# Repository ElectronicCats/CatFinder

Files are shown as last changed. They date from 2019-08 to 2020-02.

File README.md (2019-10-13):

# CatFinder

The Electronic Cats along with The Inventor's House have developed a new development kit for a Mars Rover in which almost everyone can participate

"The CatFinder" is an exploration vehicle that collects data from the environment in which it travels.

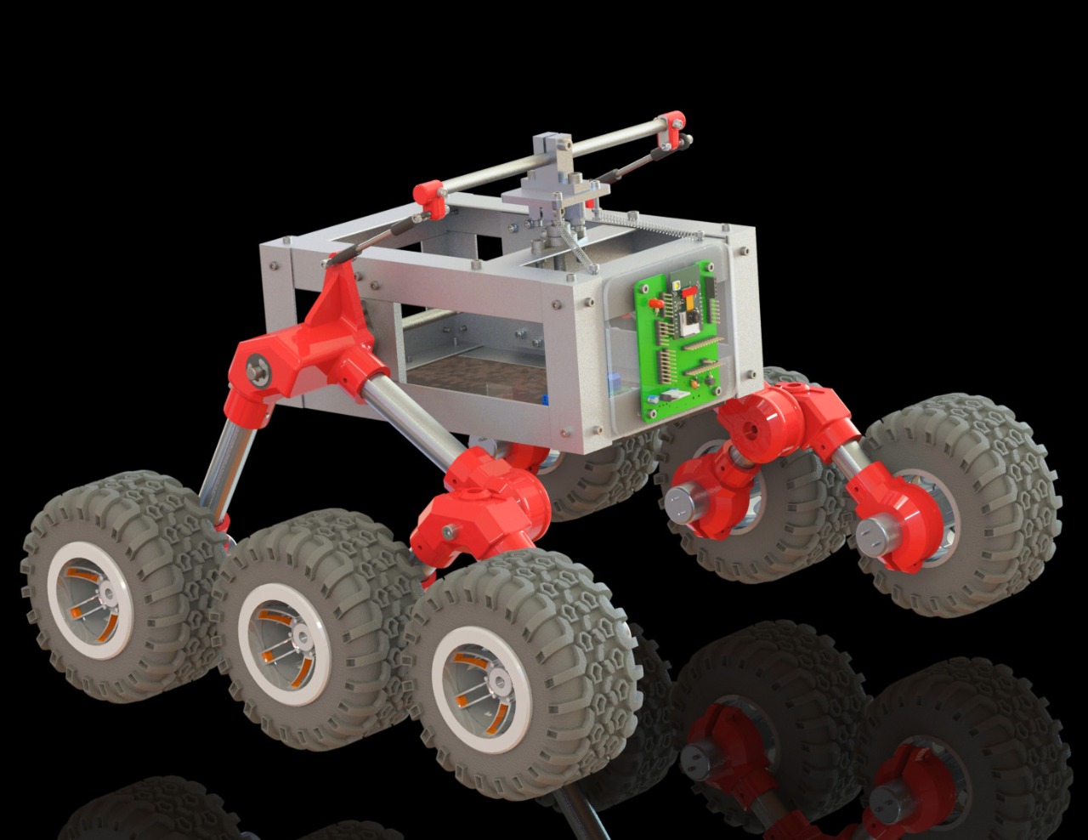
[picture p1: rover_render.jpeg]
Rover Render


The CatFinder Rover is cappable of transmit:

- Humidity
- Atmosphere pressure
- Temperature 
- CO2 levels in ppm
- TVOC levels in ppb 
- Position with acelerometer and gyroscope
- Video broadcasting.

Yes! we're capable of getting data, control the motors and transmitting video, through WiFi thanks to the ESP32-CAM and the [Bast Pro Mini](https://github.com/ElectronicCats/Bast-Pro-Mini-M0) (Which is a devBoard fully compatible with the Arduino Pro Mini).

## Licence ##

Firmware released under an GNU AGPL v3.0 license. See the LICENSE file for more information.

Hardware released under an CERN Open Hardware Licence v1.2. See the LICENSE_HARDWARE file for more information.

Electronic Cats is a registered trademark, please do not use if you sell these PCBs.

Electronic Cats invests time and resources providing this open source design, please support Electronic Cats and open-source hardware by purchasing products from Electronic Cats!

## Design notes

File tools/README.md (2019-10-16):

# TEXT_TRANSFORM_C v1.0

Esta herramienta creada en c# tiene la función de transformar código HTML, JS y CSS o cualquier otro a texto de C,
con el fin de poder minificar código, ahorrando tiempo y espacio en memoria



Esta herramienta se encuentra como un ejecutable en la carpeta de ```/tools``` de este repositorio

# Ejecutable
 
Esta herramienta es solamente compatible con el sistema operativo  ```windows```, instrucciones de ejecución: 

* Abrir el ejecutable que encontramos dentro del repo en la carpeta  ```/tools``` el archivo ```tool_transformC_text.exe```


# Forma de uso

  * Iniciar la aplicación con doble click en el ejecutable, aparecerá lo siguiente
  * 
  
  
  * Una vez iniciado el programa se puede crear la web en algún editor de texto y pasarlo a la aplicación con solo copiar y pegar en la consola tu codigo, como el ejemplo siguiente:

 ```
 <!DOCTYPE html>
<html lang="en">
<head>
    <meta charset="UTF-8">
    <meta name="viewport" content="width=device-width, initial-scale=1.0">
    <meta http-equiv="X-UA-Compatible" content="ie=edge">
    <title>EJEMPLO DE USO</title>
</head>
<style>
    *{
        margin: 0;
        padding: 0;
    }
    body{
        background-color: #f2f2f2;
    }
</style>
<body>
    <h1 class="title">Cat Finder</h1>
    <img src="https://electroniccats.com/wp-content/uploads/2018/01/logo-75.png" alt="Logo" />
    <p class="subtitle center">:3</p>
    <script>
        console.log('Son chidos los de Electronic Cats!');
    </script>
</body>
</html>
 ```
 Con esto se obtendra el codigo listo para C y quedara de la siguiente forma:
 
 
 
 * Una vez listo para concluir solo es necesario presionar enter y escribir ```ok.``` después de haber hecho esto nos se obtendra la siguiente salida
 
 ```<!DOCTYPE html><html lang=\"en\"><head><meta charset=\"UTF-8\"><meta name=\"viewport\" content=\"width=device-width, initial-scale=1.0\"><meta http-equiv=\"X-UA-Compatible\" content=\"ie=edge\"><title>EJEMPLO DE USO</title></head><style>*{margin: 0;padding: 0;}body{background-color: #f2f2f2;}</style><body><h1 class=\"title\">Cat Finder</h1>\"Logo\"<p class=\"subtitle center\">:3</p><script>console.log('Son chidos los de Electronic Cats!')</script></body></html>```
 
 listo para pegar en una sola linea de codigo en C, como el siguiente ejemplo
 
```SendData = "<!DOCTYPE html><html lang=\"en\"><head><meta charset=\"UTF-8\"><meta name=\"viewport\" content=\"width=device-width, initial-scale=1.0\"><meta http-equiv=\"X-UA-Compatible\" content=\"ie=edge\"><title>EJEMPLO DE USO</title></head><style>*{margin: 0;padding: 0;}body{background-color: #f2f2f2;}</style><body><h1 class=\"title\">Cat Finder</h1><img src=\"https://electroniccats.com/wp-content/uploads/2018/01/logo-75.png\" alt=\"Logo\" /><p class=\"subtitle center\">:3</p><script>console.log('Son chidos los de Electronic Cats!')</script></body></html>";```

# Recomendaciones

  * Es importante saber que cada línea de código escrita con js tendra que terminar con su ```;``` ya que al final de el proceso se entrega una sola linea de codigo y esto en js marcaria un error al momento de ejecutarlo en el navegador si no termina cada línea con su ```;```

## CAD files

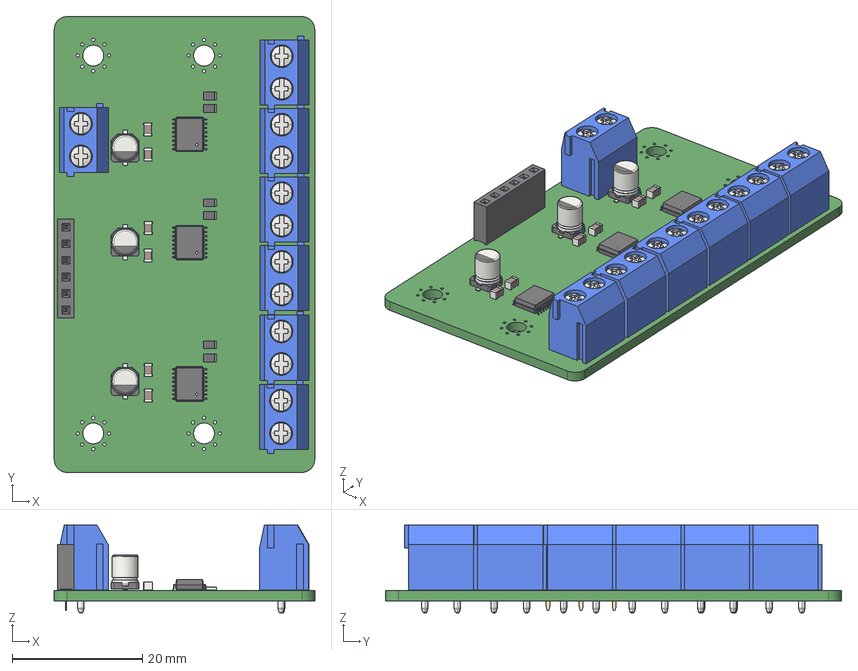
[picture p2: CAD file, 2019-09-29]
Electronics/Hardware/cat_finder_motors/cat_finder_motors.stp
40.0 x 70.0 x 13.5 mm

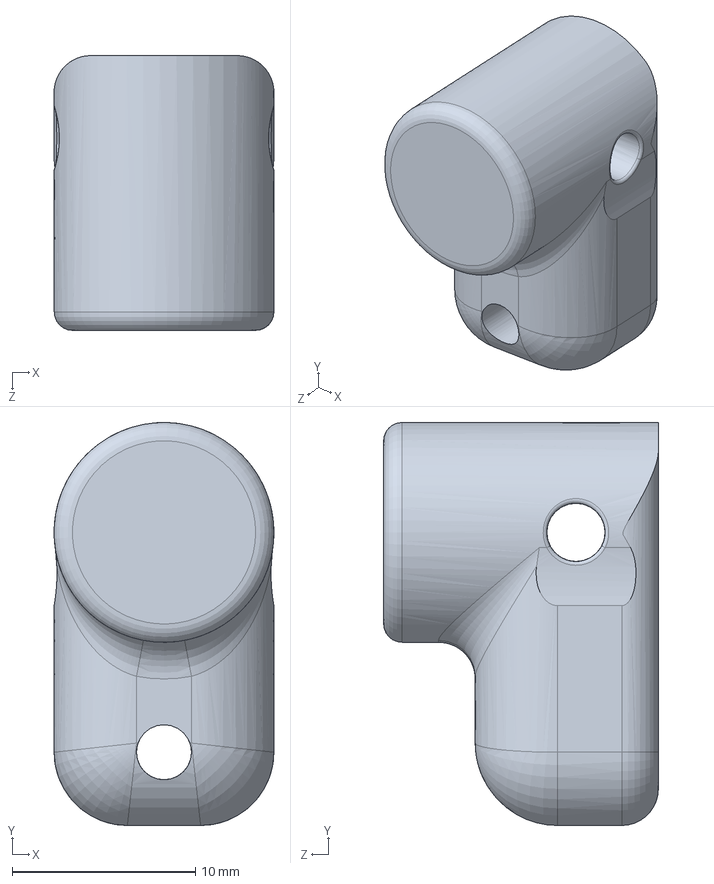
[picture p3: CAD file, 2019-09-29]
Mechanics/3D_Printing/SLDPRT/Tapon2.SLDPRT
12.0 x 22.0 x 15.0 mm

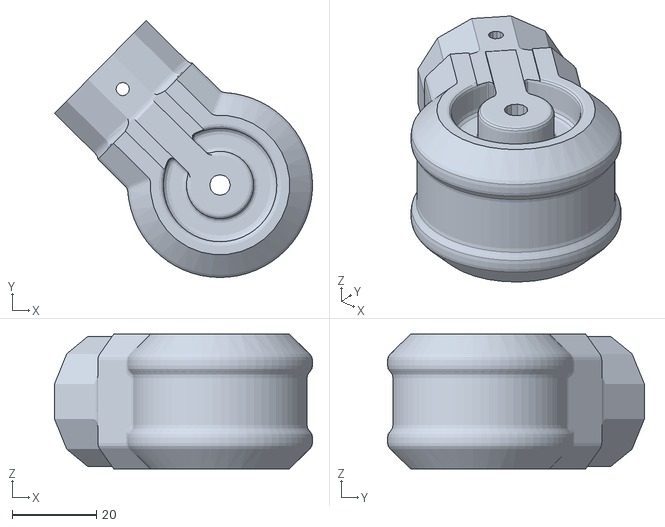
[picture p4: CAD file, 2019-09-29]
Mechanics/3D_Printing/Stl/Union_Y_delantera1.STL
61.4 x 61.1 x 32.0

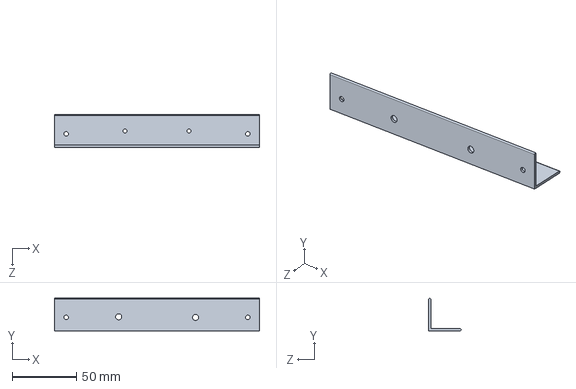
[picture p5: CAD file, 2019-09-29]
Mechanics/SolidWorks/Frontales de Caja.SLDPRT
160.0 x 25.4 x 25.4 mm

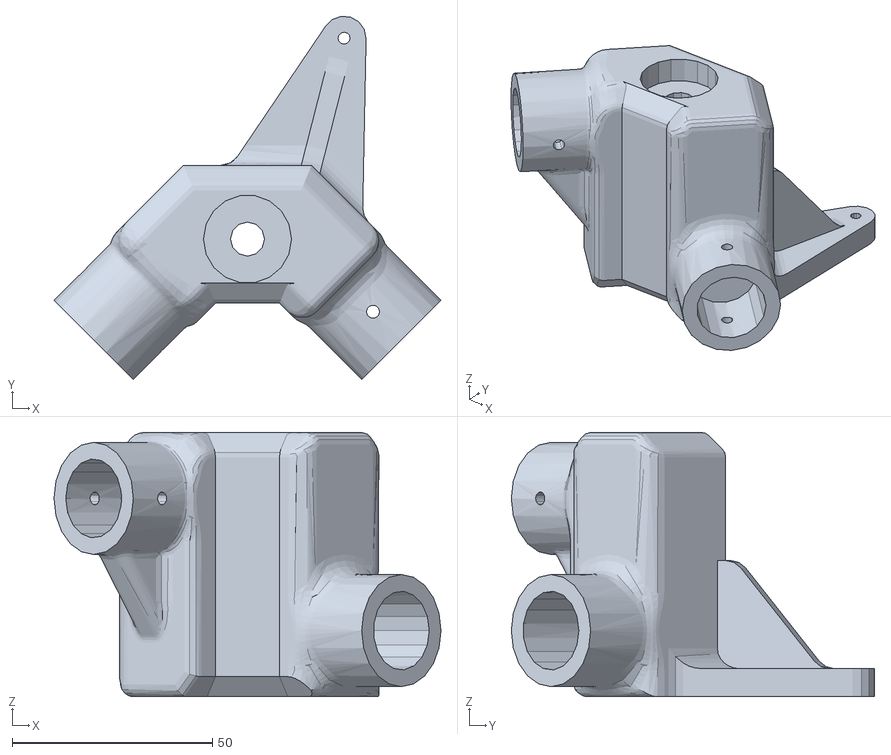
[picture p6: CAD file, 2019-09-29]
Mechanics/3D_Printing/Stl/doble2.STL
96.6 x 90.7 x 66.0

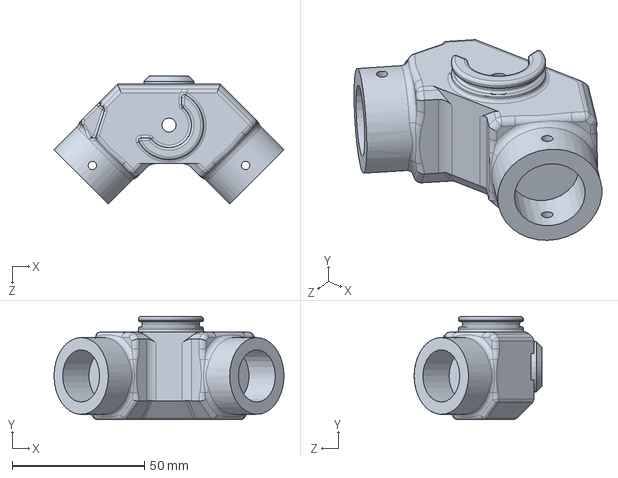
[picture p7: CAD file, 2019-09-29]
Mechanics/3D_Printing/SLDPRT/Ydelantera1.sldprt
86.8 x 39.0 x 48.2 mm

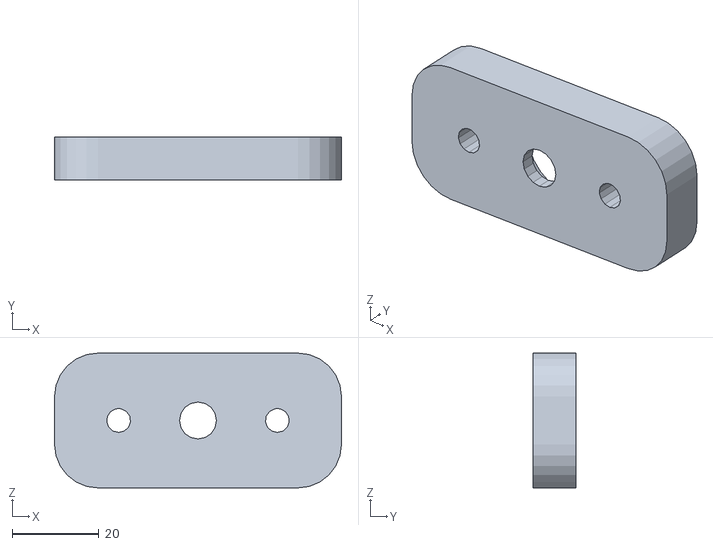
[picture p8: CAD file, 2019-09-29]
Mechanics/3D_Printing/Stl/soporte baleros.STL
66.0 x 10.0 x 31.0

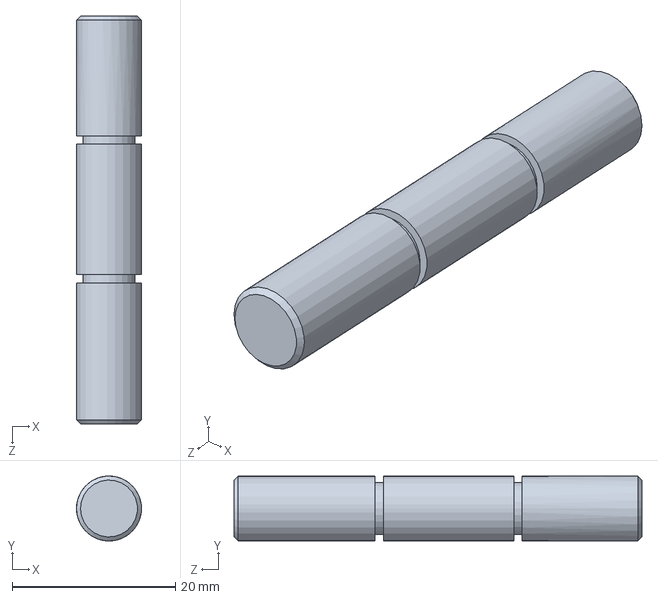
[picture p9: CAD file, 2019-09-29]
Mechanics/SolidWorks/Mini eje.SLDPRT
7.98 x 7.96 x 50.0 mm

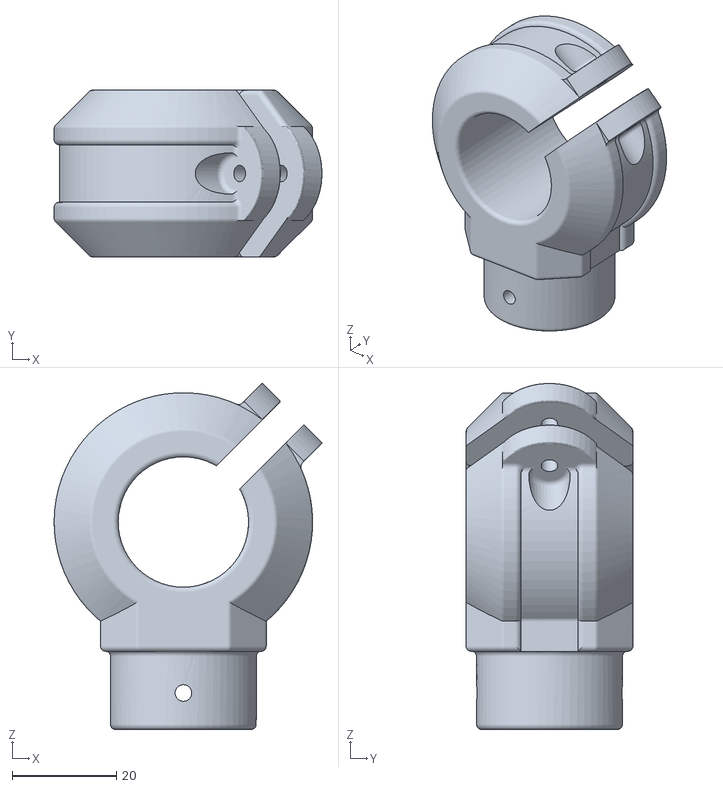
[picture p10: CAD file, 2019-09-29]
Mechanics/3D_Printing/Stl/Ruedas_Suport.STL
51.4 x 32.0 x 66.4

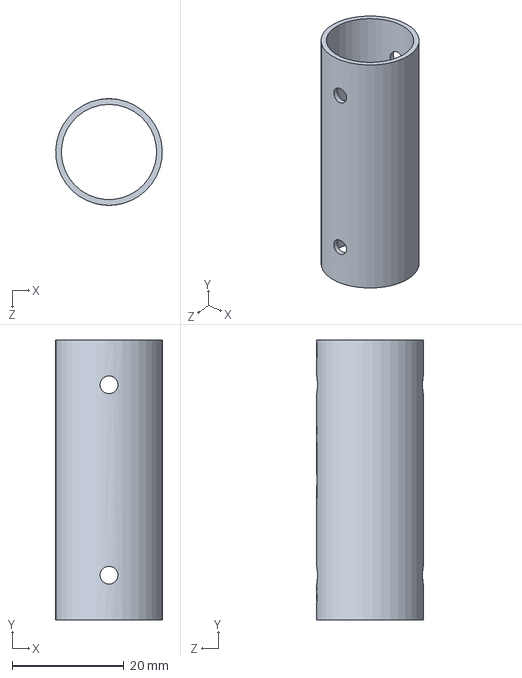
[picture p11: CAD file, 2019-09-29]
Mechanics/SolidWorks/tubo50mm.SLDPRT
19.0 x 50.0 x 19.1 mm

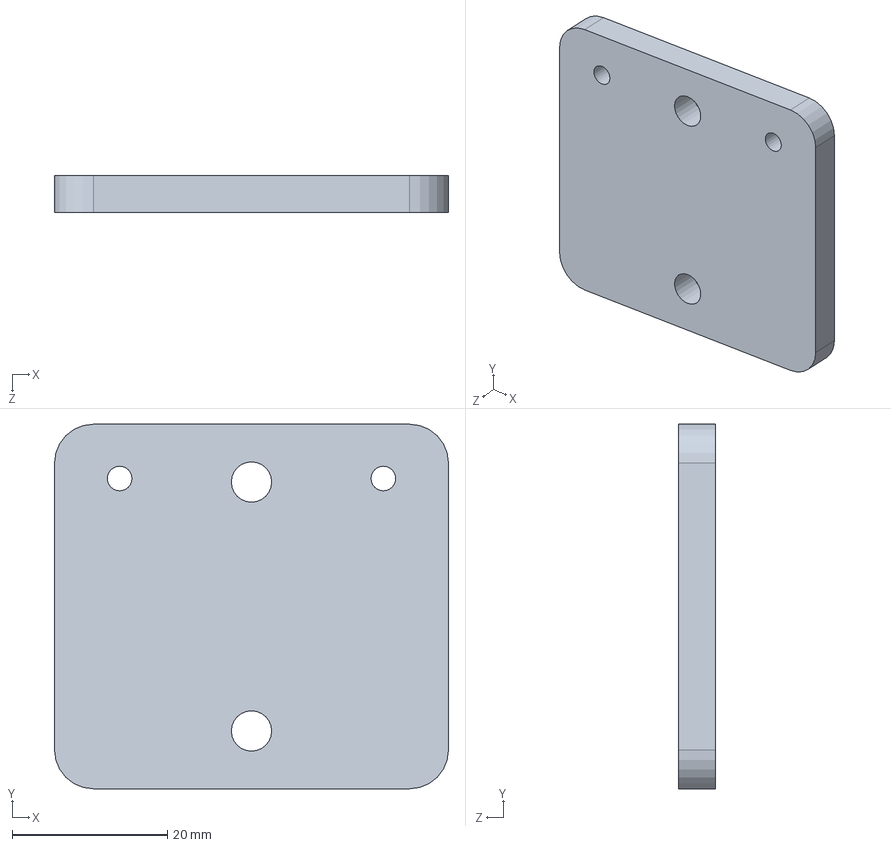
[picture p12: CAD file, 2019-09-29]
Mechanics/SolidWorks/Lamina para sk8.SLDPRT
50.8 x 47.0 x 4.76 mm

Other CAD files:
Mechanics/3D_Printing/SLDPRT/Tapon1.SLDPRT
Mechanics/3D_Printing/SLDPRT/YGeneral1.SLDPRT
Mechanics/3D_Printing/SLDPRT/YGeneral2.SLDPRT
Mechanics/3D_Printing/Stl/doble1.STL
Mechanics/3D_Printing/SLDPRT/Ydelantera2.sldprt
Mechanics/3D_Printing/Stl/Union_Y_delantera2.STL
Mechanics/3D_Printing/SLDPRT/Union a Y delantera 1.SLDPRT
Mechanics/3D_Printing/SLDPRT/Union a Y delantera2.SLDPRT
Mechanics/3D_Printing/Stl/Tapon1.STL
Mechanics/3D_Printing/Stl/Tapon2.STL
Mechanics/3D_Printing/Stl/Y_delantera1.STL
Mechanics/3D_Printing/Stl/Y_delantera2.STL
Mechanics/SolidWorks/Acrilico Base.SLDPRT
Mechanics/SolidWorks/Acrilico frontal.SLDPRT
Mechanics/SolidWorks/Acrilico.SLDPRT
Mechanics/SolidWorks/Ajuste de rotulas.SLDPRT
Mechanics/SolidWorks/Balero 608.SLDPRT
Mechanics/SolidWorks/Base para Chumacera.SLDPRT
Mechanics/SolidWorks/Base para resortes .SLDPRT
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

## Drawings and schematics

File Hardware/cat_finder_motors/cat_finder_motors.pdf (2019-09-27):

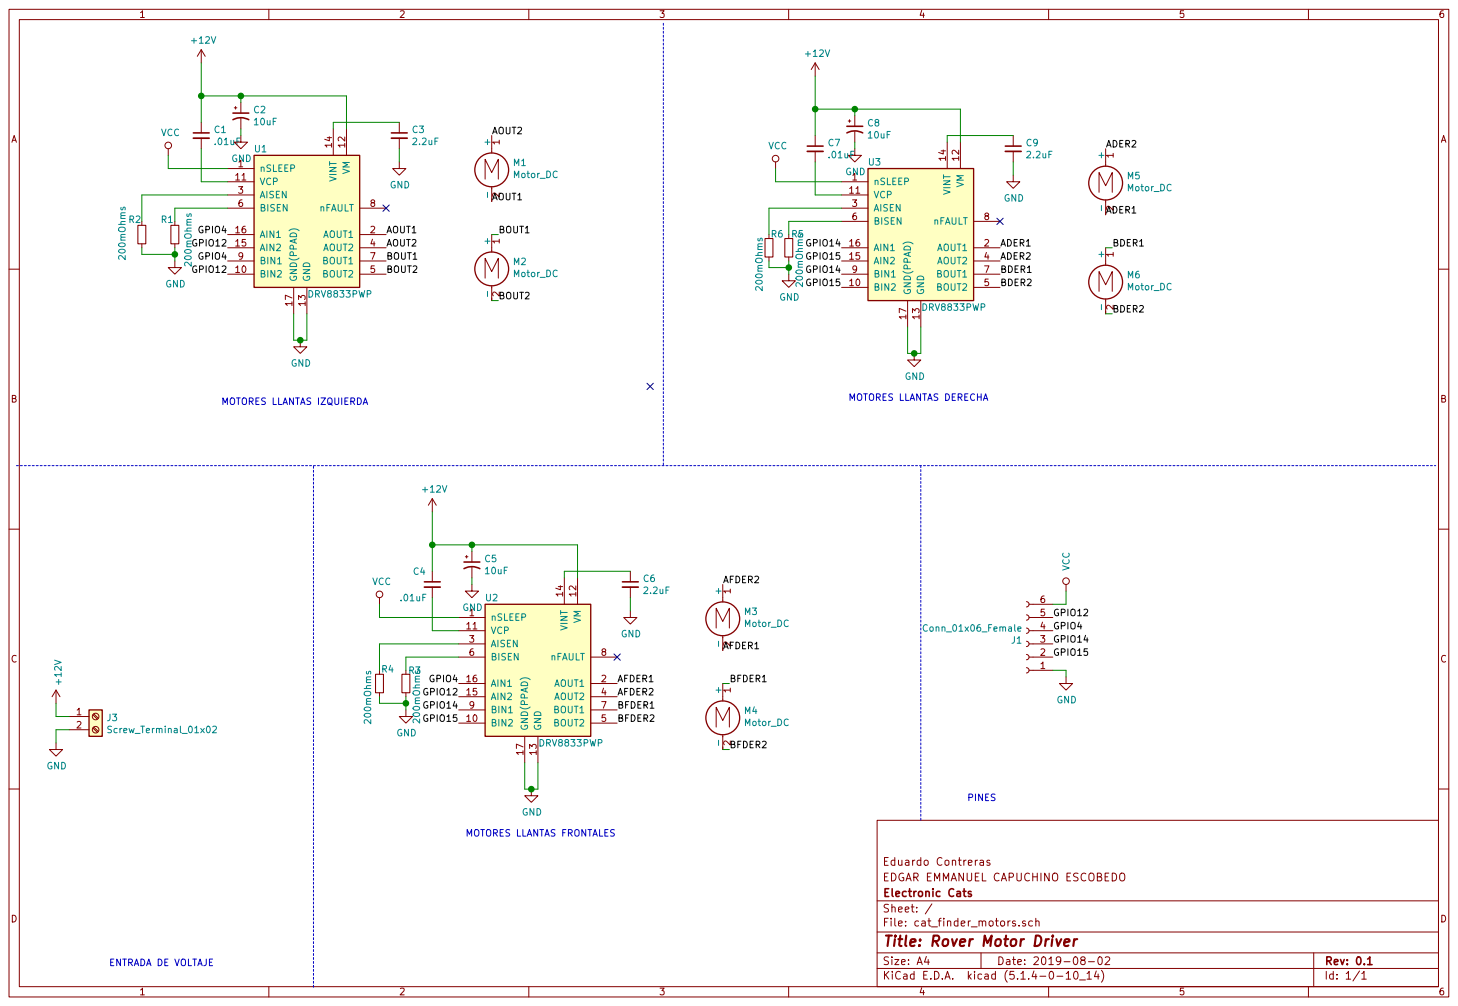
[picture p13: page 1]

Eduardo Contreras
File: cat_finder_motors.sch Sheet: / Electronic Cats EDGAR EMMANUEL CAPUCHINO ESCOBEDO

Id: 1/1 Title: Rover Motor Driver

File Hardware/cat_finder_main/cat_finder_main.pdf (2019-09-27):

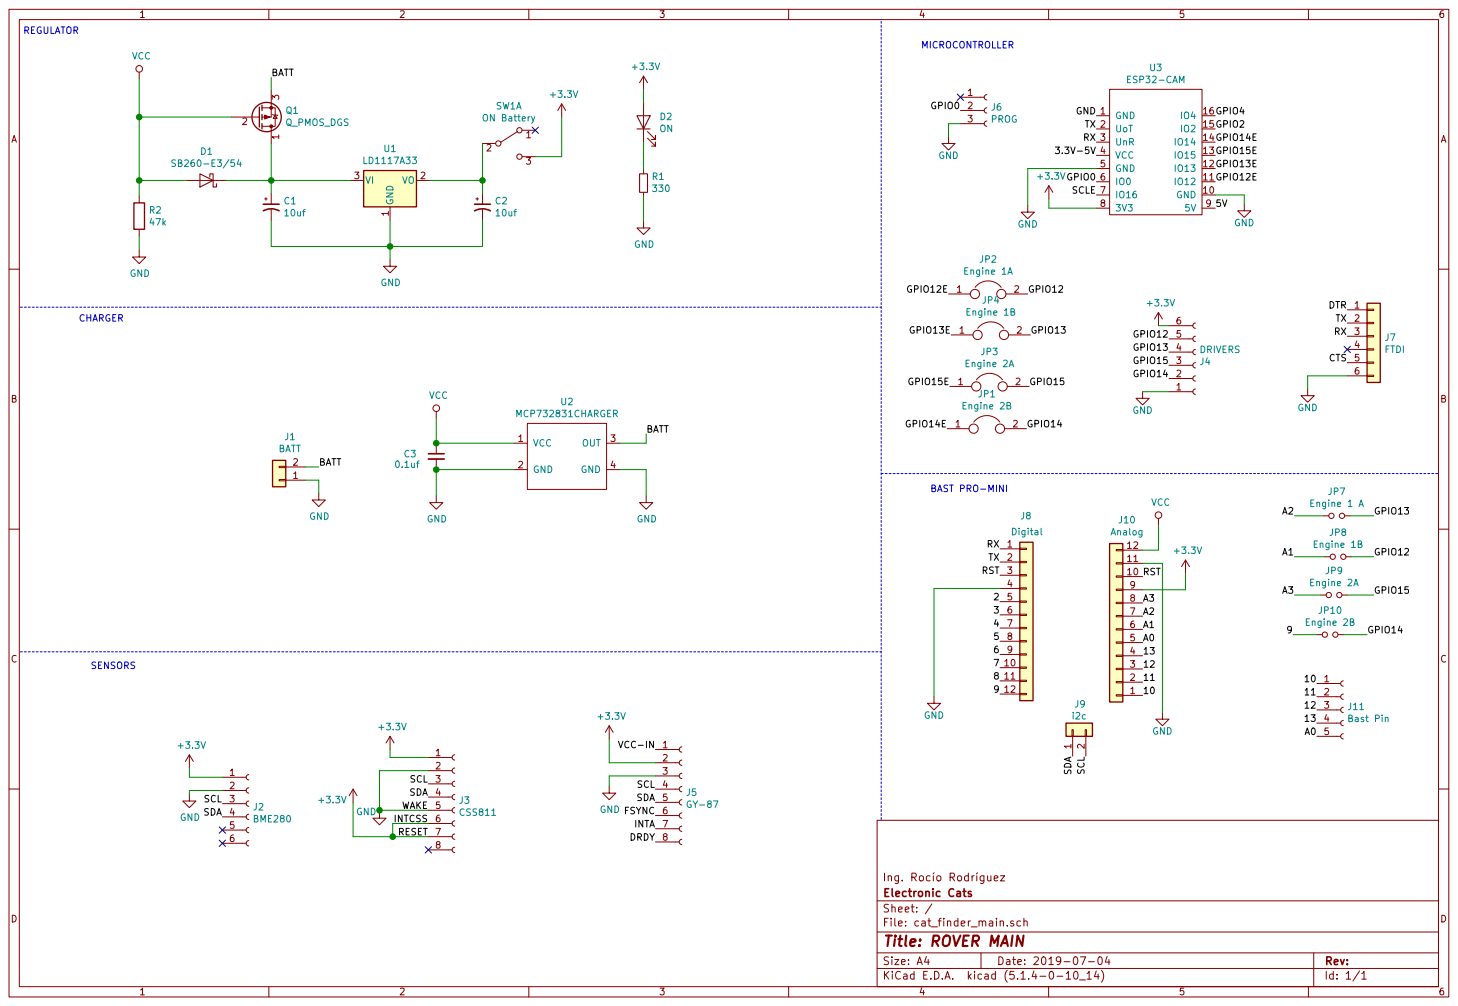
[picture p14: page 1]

Ing. Rocío Rodríguez
File: cat_finder_main.sch Sheet: / Electronic Cats

Id: 1/1 Title: ROVER MAIN

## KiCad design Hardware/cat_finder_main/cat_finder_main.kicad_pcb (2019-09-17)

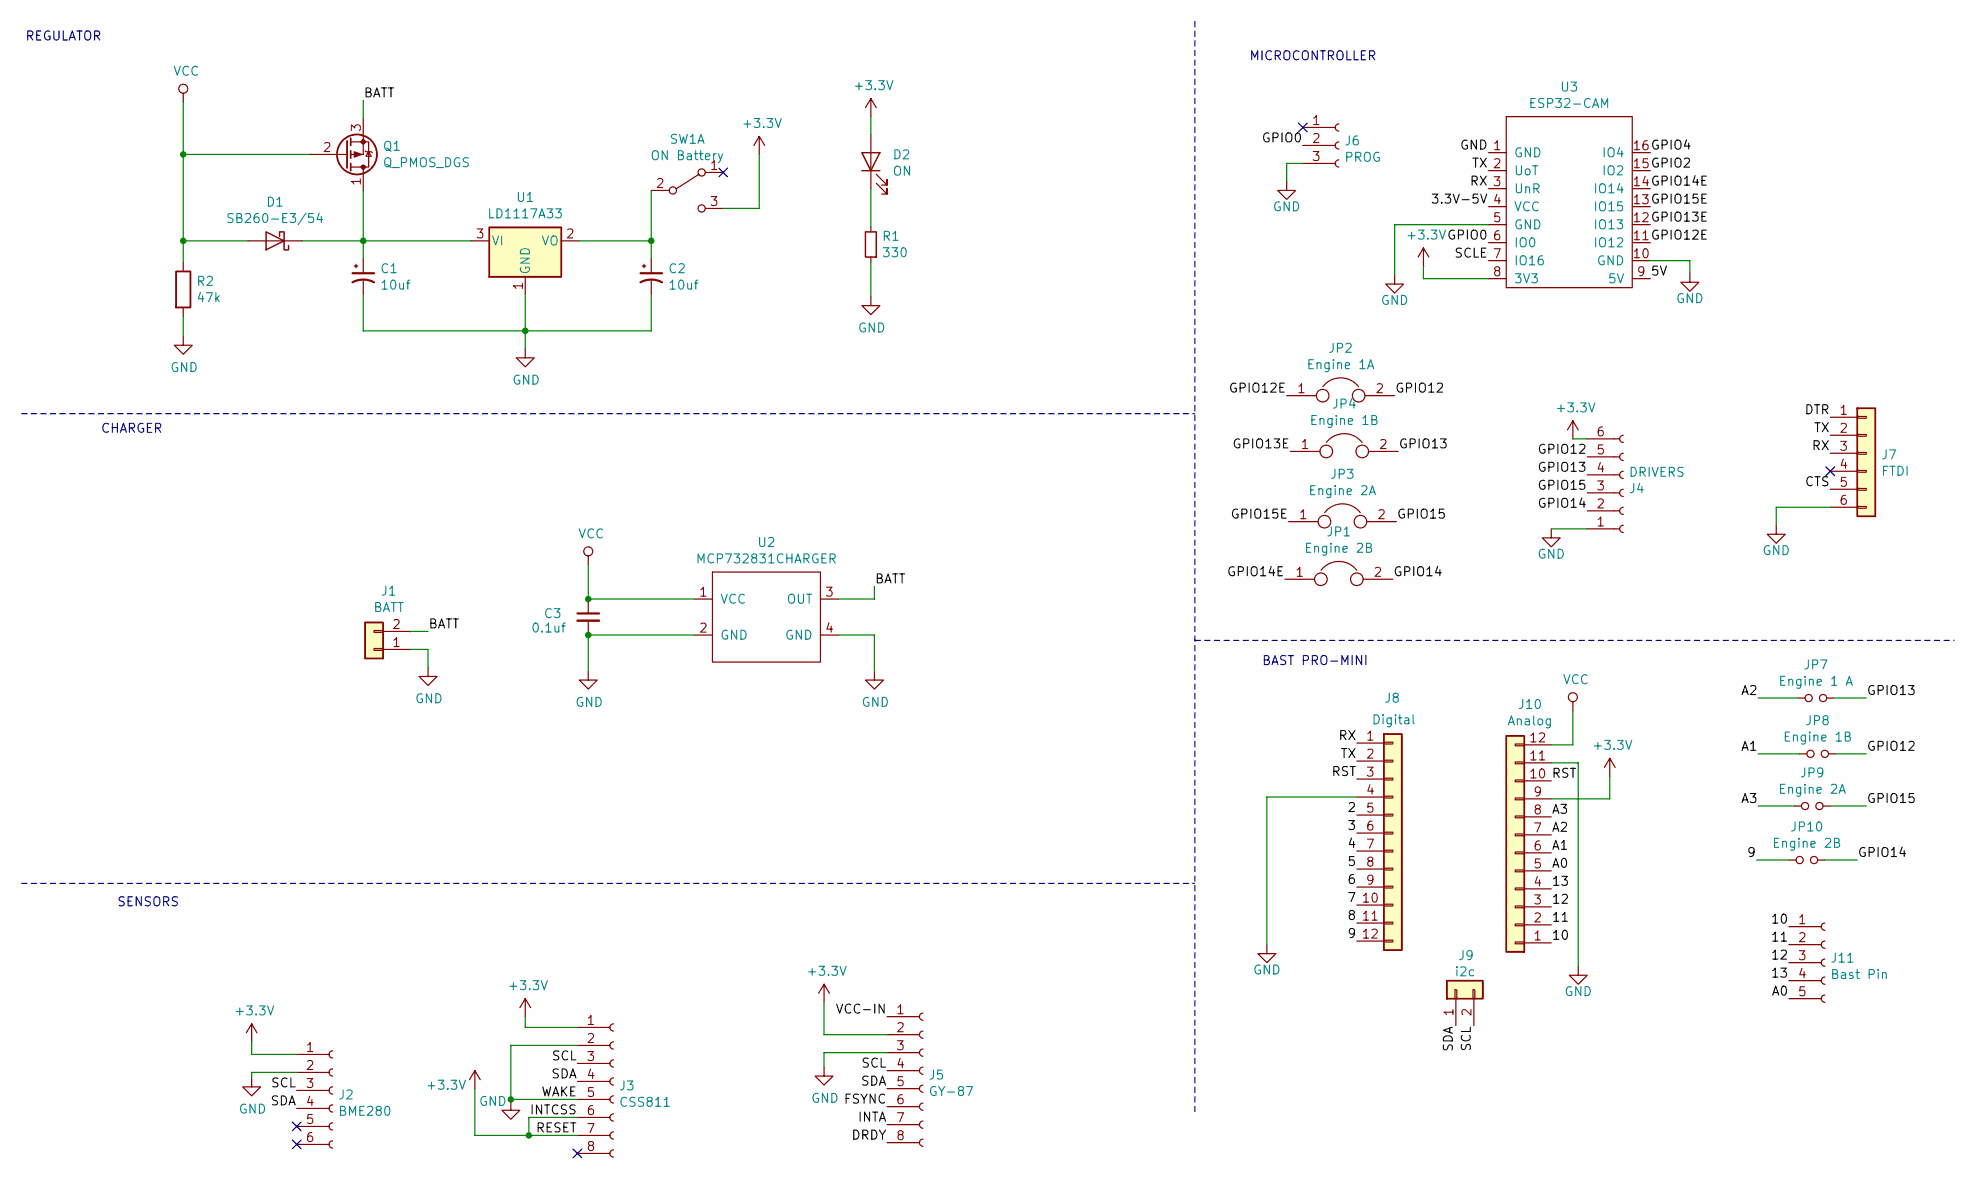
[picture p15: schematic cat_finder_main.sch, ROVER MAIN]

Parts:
C1, C2: 10uf; CP_Radial_D5.0mm_P2.00mm
C3: 0.1uf; C_Disc_D5.0mm_W2.5mm_P5.00mm
D1: SB260-E3/54; D_A-405_P7.62mm_Horizontal
D2: ON; LED_D5.0mm
J1: BATT; TerminalBlock_bornier-2_P5.08mm
J2: BME280; PinHeader_1x06_P2.54mm_Vertical
J3: CSS811; PinHeader_1x08_P2.54mm_Vertical
J4: DRIVERS; PinHeader_1x06_P2.54mm_Vertical
J5: GY-87; PinHeader_1x08_P2.54mm_Vertical
J6: PROG; PinHeader_1x03_P2.54mm_Vertical
J7: FTDI; PinHeader_1x06_P2.54mm_Vertical
J8: Digital; PinHeader_1x12_P2.54mm_Vertical
J9: i2c; PinHeader_1x02_P2.54mm_Vertical
J10: Analog; PinHeader_1x12_P2.54mm_Vertical
J11: Bast Pin; PinSocket_1x05_P2.54mm_Vertical
JP1: Engine 2B; SolderJumper-2_P1.3mm_Bridged_RoundedPad1.0x1.5mm
JP2: Engine 1A; SolderJumper-2_P1.3mm_Bridged_RoundedPad1.0x1.5mm
JP3: Engine 2A; SolderJumper-2_P1.3mm_Bridged_RoundedPad1.0x1.5mm
JP4: Engine 1B; SolderJumper-2_P1.3mm_Bridged_RoundedPad1.0x1.5mm
JP7: Engine 1 A; SolderJumper-2_P1.3mm_Open_RoundedPad1.0x1.5mm
JP8: Engine 1B; SolderJumper-2_P1.3mm_Open_RoundedPad1.0x1.5mm
JP9: Engine 2A; SolderJumper-2_P1.3mm_Open_RoundedPad1.0x1.5mm
JP10: Engine 2B; SolderJumper-2_P1.3mm_Open_RoundedPad1.0x1.5mm
Q1: Q_PMOS_DGS; TO-92_Inline
R1: 330; R_Axial_DIN0207_L6.3mm_D2.5mm_P10.16mm_Horizontal
R2: 47k; R_Axial_DIN0207_L6.3mm_D2.5mm_P10.16mm_Horizontal
SW1: ON Battery; SW_1825116-1
U1: LD1117A33; TO-220-3_Vertical
U2: MCP732831CHARGER; charger_EC_3.3V_battery
U3: ESP32-CAM

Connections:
+3V3: D2.2 (A), J2.1, J3.1, J3.6, J3.7, J4.6, J5.2, J10.9, SW1.3 (C), U3.8 (3V3)
/2: J8.5
/3: J8.6
/3.3V-5V: U3.4 (VCC)
/4: J8.7
/5: J8.8
/5V: U3.9 (5V)
/6: J8.9
/7: J8.10
/8: J8.11
/9: J8.12, JP10.1
/10: J10.1, J11.1
/11: J10.2, J11.2
/12: J10.3, J11.3
/13: J10.4, J11.4
/A0: J10.5, J11.5
/A1: J10.6, JP8.1
/A2: J10.7, JP7.1
/A3: J10.8, JP9.1
/BATT: J1.2, Q1.3 (S), U2.3 (OUT)
/CTS: J7.5
/DRDY: J5.8
/DTR: J7.1
/FSYNC: J5.6
/GPIO0: J6.2, U3.6 (IO0)
/GPIO2: U3.15 (IO2)
/GPIO4: U3.16 (IO4)
/GPIO12: J4.5, JP2.2, JP8.2
/GPIO12E: JP2.1, U3.11 (IO12)
/GPIO13: J4.4, JP4.2, JP7.2
/GPIO13E: JP4.1, U3.12 (IO13)
/GPIO14: J4.2, JP1.2, JP10.2
/GPIO14E: JP1.1, U3.14 (IO14)
/GPIO15: J4.3, JP3.2, JP9.2
/GPIO15E: JP3.1, U3.13 (IO15)
/INTA: J5.7
/RST: J8.3, J10.10
/RX: J7.3, J8.1, U3.3 (UnR)
/SCL: J2.3, J3.3, J5.4, J9.2
/SCLE: U3.7 (IO16)
/SDA: J2.4, J3.4, J5.5, J9.1
/TX: J7.2, J8.2, U3.2 (UoT)
/VCC-IN: J5.1
GND: C1.2, C2.2, C3.2, J1.1, J2.2, J3.2, J3.5, J4.1, J5.3, J6.3, J7.6, J8.4, J10.11, R1.1, R2.2, U1.1 (GND), U2.2 (GND), U2.4 (GND), U3.1 (GND), U3.5 (GND), U3.10 (GND)
unnamed: C1.1, D1.1 (K), Q1.1 (D), U1.3 (VI)
unnamed: C2.1, SW1.2 (B), U1.2 (VO)
unnamed: D2.1 (K), R1.2
VCC: C3.1, D1.2 (A), J10.12, Q1.2 (G), R2.1, U2.1 (VCC)

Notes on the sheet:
REGULATOR
CHARGER
SENSORS
MICROCONTROLLER
BAST PRO-MINI

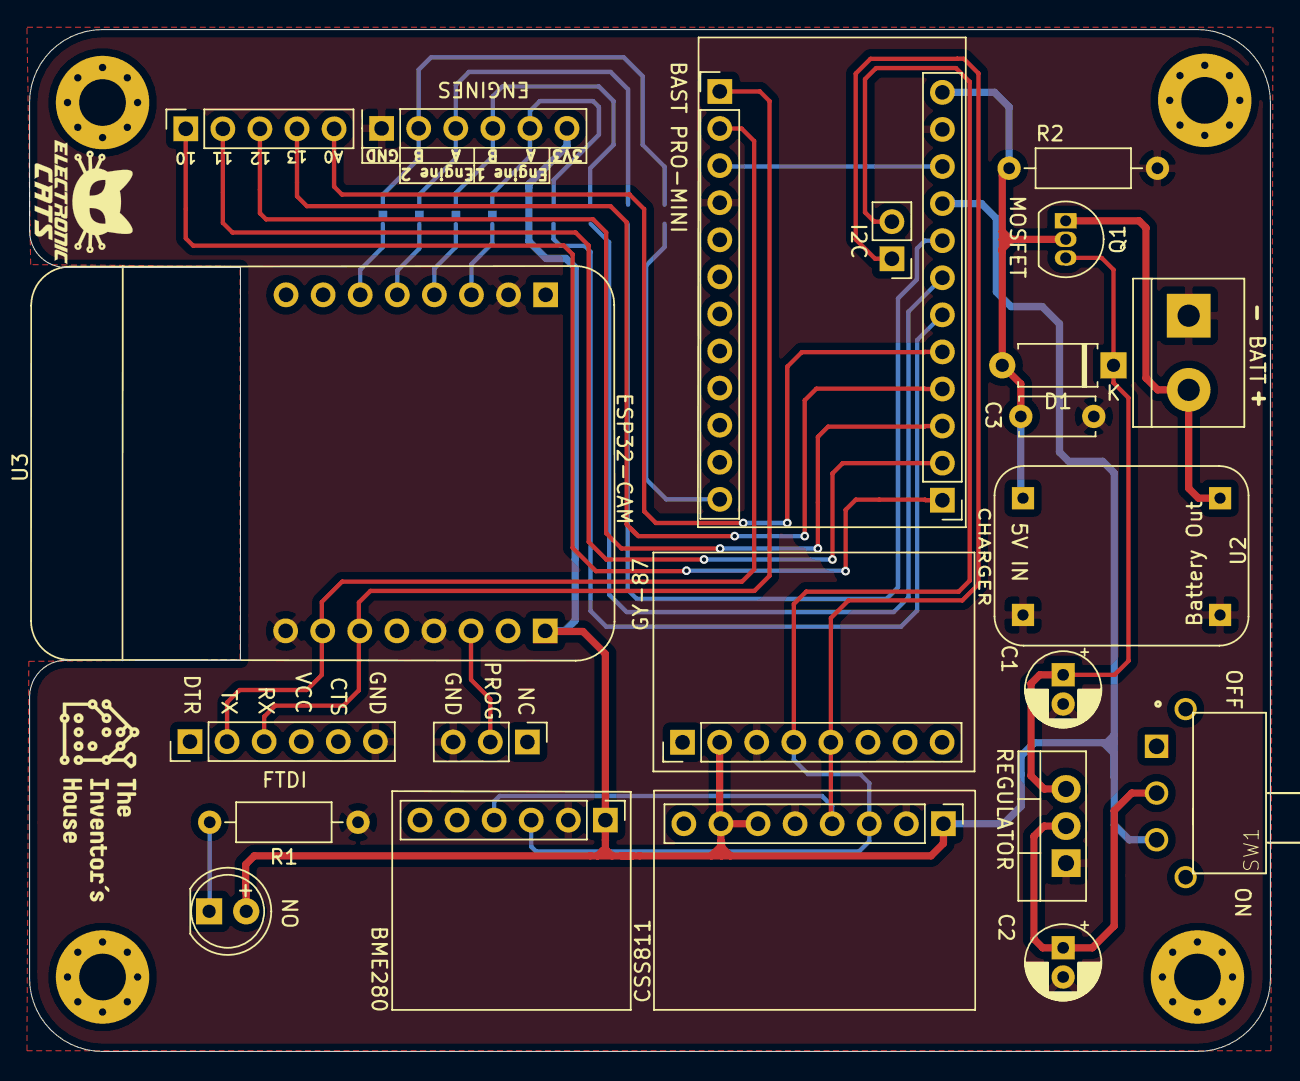
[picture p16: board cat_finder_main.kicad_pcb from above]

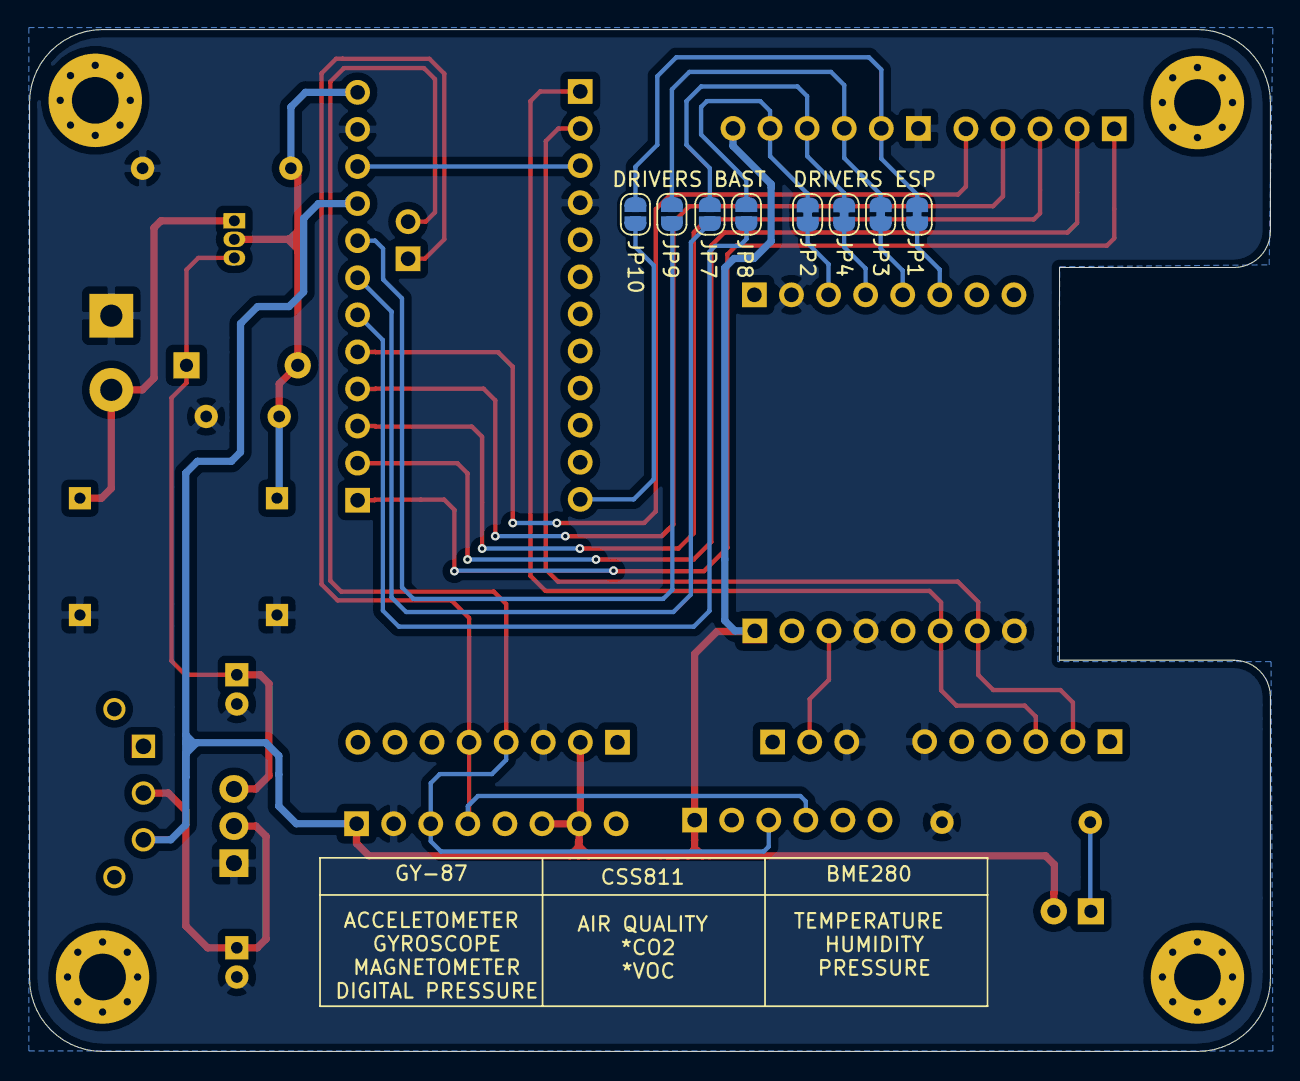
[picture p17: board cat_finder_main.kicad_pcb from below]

Board: 2 copper layers, 85.0 x 70.0 mm, 31 parts (8 on the bottom side), 30 nets.

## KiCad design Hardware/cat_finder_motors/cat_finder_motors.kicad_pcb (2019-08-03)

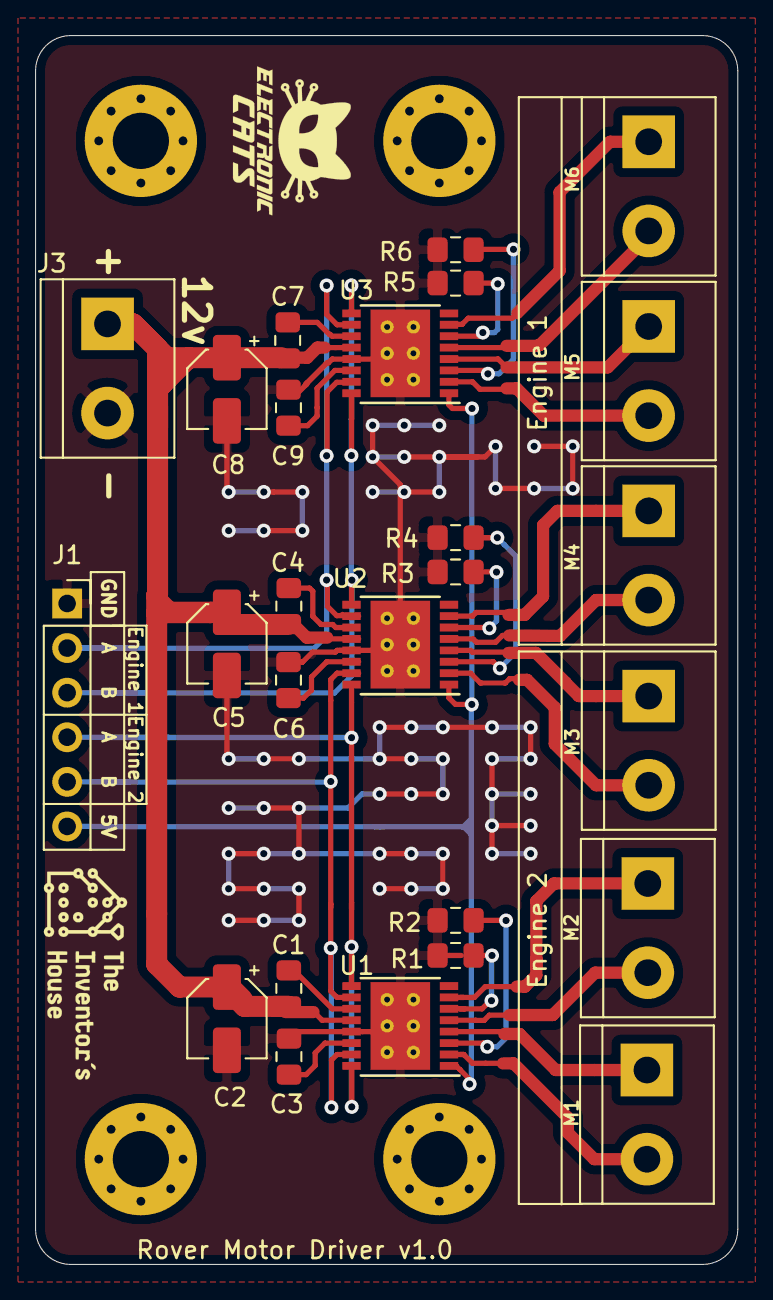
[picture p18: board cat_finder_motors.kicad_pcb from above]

Board: 2 copper layers, 40.0 x 70.0 mm, 26 parts (0 on the bottom side), 31 nets.

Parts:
C1, C4, C7: .01uF; C_0805_2012Metric_Pad1.15x1.40mm_HandSolder
C2, C5, C8: 10uF; CP_Elec_4x5.4
C3, C6, C9: 2.2uF; C_0805_2012Metric_Pad1.15x1.40mm_HandSolder
J1: Conn_01x06_Female; PinSocket_1x06_P2.54mm_Vertical
J3: Screw_Terminal_01x02; TerminalBlock_bornier-2_P5.08mm
M1, M2, M3, M4, M5, M6: Motor_DC; TerminalBlock_bornier-2_P5.08mm
R1, R2, R6: 200mOhms; R_0805_2012Metric_Pad1.15x1.40mm_HandSolder
R3, R4, R5: 200mOhm; R_0805_2012Metric_Pad1.15x1.40mm_HandSolder
U1, U2, U3: DRV8833PWP; HTSSOP-16-1EP_4.4x5mm_P0.65mm_EP3.4x5mm_Mask2.46x2.31mm_The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

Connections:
+12V: C1.1, C2.1, C4.1, C5.1, C7.1, C8.1, J3.1, U1.12, U2.12, U3.12
/ADER1: M5.2, U3.2
/ADER2: M5.1, U3.4
/AFDER1: M3.2, U2.2
/AFDER2: M3.1, U2.4
/AOUT1: M1.2, U1.2
/AOUT2: M1.1, U1.4
/BDER1: M6.1, U3.7
/BDER2: M6.2, U3.5
/BFDER1: M4.1, U2.7
/BFDER2: M4.2, U2.5
/BOUT1: M2.1, U1.7
/BOUT2: M2.2, U1.5
/GPIO4: J1.4, U1.9, U1.16, U2.16
/GPIO12: J1.5, U1.10, U1.15, U2.15
/GPIO14: J1.3, U2.9, U3.9, U3.16
/GPIO15: J1.2, U2.10, U3.10, U3.15
GND: C2.2, C3.2, C5.2, C6.2, C8.2, C9.2, J1.1, J3.2, R1.2, R2.2, R3.2, R4.2, R5.2, R6.2, U1.13, U1.17, U2.13, U2.17, U3.13, U3.17
unnamed: C1.2, U1.11
unnamed: C3.1, U1.14
unnamed: C4.2, U2.11
unnamed: C6.1, U2.14
unnamed: C7.2, U3.11
unnamed: C9.1, U3.14
unnamed: R1.1, U1.6
unnamed: R2.1, U1.3
unnamed: R3.1, U2.6
unnamed: R4.1, U2.3
unnamed: R5.1, U3.6
unnamed: R6.1, U3.3
VCC: J1.6, U1.1, U2.1, U3.1

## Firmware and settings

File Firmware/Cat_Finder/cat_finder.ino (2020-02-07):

/************************************************************
  SPANISH
  Cat Finder 1.0.1
  Cat Finder - Rover Educativo
  Rocio Rosales @ Electronic Cats
  Eduardo Contreras @ Electronic Cats
  Original Creation Date: Sep 23, 2019
  https://github.com/ElectronicCats/Cat_Finder

  Este ejemplos demuestra el funcionamiento basico de los sensores y funcionalidad
  basica del Cat Finder Kit de Rover Educativo
  http://electroniccats.com

  Especificaciones del entorno de Desarrollo:
  IDE: Arduino 1.8.9
  ESP32 Core: 1.0.2
  Plataforma de Hardware:
  Kit Cat Finder
  - ESP32 CAM


  Este código es beerware si tu me ves ( o cualquier otro miembro de Electronic Cats)
  a nivel local, y tu has encontrado nuestro código útil ,
  por favor comprar una ronda de cervezas!

  Distribuido como; no se da ninguna garantía.
************************************************************/

/************************************************************
  ENGLISH
  Cat Finder 1.0.1
  Cat Finer - Rover
  Rocio Rosales @ Electronic Cats
  Eduardo Contreras @ Electronic Cats
  Original Creation Date: Sep 23, 2019
  https://github.com/ElectronicCats/Cat_Finder

  This example demonstrates how to use ESP32 Cam

  Development environment specifics:
  IDE: Arduino 1.8.4
  Hardware Platform:
  Kit Can Finder
  - ESP32 CAM

  This code is beerware; if you see me (or any other Electronic Cats
  member) at the local, and you've found our code helpful,
  please buy us a round!

  Distributed as-is; no warranty is given.
*/

#include "esp_camera.h"
#include <WiFi.h>

// WARNING!!! Make sure that you have either selected ESP32 Wrover Module,
//            or another board which has PSRAM enabled


const int motorUnoA = 15; // Pin controlado por PWM 
const int motorUnoB = 14; // Pin controlado por PWM 
const int motorDosA = 12; // Pin controlado por PWM 
const int motorDosB = 13; // Pin controlado por PWM 

extern int go_front;
extern int go_back;
extern int go_right;
extern int go_left;
extern int datain;
String str = "";

void startCameraServer();

#define PWDN_GPIO_NUM     32
#define RESET_GPIO_NUM    -1
#define XCLK_GPIO_NUM      0
#define SIOD_GPIO_NUM     26
#define SIOC_GPIO_NUM     27

#define Y9_GPIO_NUM       35
#define Y8_GPIO_NUM       34
#define Y7_GPIO_NUM       39
#define Y6_GPIO_NUM       36
#define Y5_GPIO_NUM       21
#define Y4_GPIO_NUM       19
#define Y3_GPIO_NUM       18
#define Y2_GPIO_NUM        5
#define VSYNC_GPIO_NUM    25
#define HREF_GPIO_NUM     23
#define PCLK_GPIO_NUM     22

char ssid[15]; //Create a Unique AP from MAC address
const byte DNS_PORT = 53;
IPAddress apIP(192, 168, 4, 1);

void setup() {
  Serial.begin(115200);
  Serial.setDebugOutput(true);
  pinMode(motorUnoB, OUTPUT);
  pinMode(motorDosA, OUTPUT);
  pinMode(motorDosB, OUTPUT);
  pinMode(motorUnoA, OUTPUT);
  pinMode(4, OUTPUT);

   //WiFi Access point
  WiFi.mode(WIFI_AP);
  WiFi.softAPConfig(apIP, apIP, IPAddress(255, 255, 0, 0));
  
  uint64_t chipid=ESP.getEfuseMac();//The chip ID is essentially its MAC address(length: 6 bytes).
  uint16_t chip = (uint16_t)(chipid>>32);
  snprintf(ssid,15,"Cat Finder-%04X",chip);
  WiFi.softAP(ssid);

  //init camera
  startCameraServer();

  //Camera config
  camera_config_t config;
  config.ledc_channel = LEDC_CHANNEL_0;
  config.ledc_timer = LEDC_TIMER_0;
  config.pin_d0 = Y2_GPIO_NUM;
  config.pin_d1 = Y3_GPIO_NUM;
  config.pin_d2 = Y4_GPIO_NUM;
  config.pin_d3 = Y5_GPIO_NUM;
  config.pin_d4 = Y6_GPIO_NUM;
  config.pin_d5 = Y7_GPIO_NUM;
  config.pin_d6 = Y8_GPIO_NUM;
  config.pin_d7 = Y9_GPIO_NUM;
  config.pin_xclk = XCLK_GPIO_NUM;
  config.pin_pclk = PCLK_GPIO_NUM;
  config.pin_vsync = VSYNC_GPIO_NUM;
  config.pin_href = HREF_GPIO_NUM;
  config.pin_sscb_sda = SIOD_GPIO_NUM;
  config.pin_sscb_scl = SIOC_GPIO_NUM;
  config.pin_pwdn = PWDN_GPIO_NUM;
  config.pin_reset = RESET_GPIO_NUM;
  config.xclk_freq_hz = 20000000;
  config.pixel_format = PIXFORMAT_JPEG;
  
  //init with high specs to pre-allocate larger buffers
  if(psramFound()){
    config.frame_size = FRAMESIZE_UXGA;
    config.jpeg_quality = 10;
    config.fb_count = 2;
  } else {
    config.frame_size = FRAMESIZE_SVGA;
    config.jpeg_quality = 12;
    config.fb_count = 1;
  }

  // camera init
  esp_err_t err = esp_camera_init(&config);
  if (err != ESP_OK) {
    Serial.printf("Camera init failed with error 0x%x", err);
    return;
  }
  sensor_t * s = esp_camera_sensor_get();
  //initial sensors are flipped vertically and colors are a bit saturated
  //drop down frame size for higher initial frame rate
  s->set_framesize(s, FRAMESIZE_QVGA);
}

void loop() {
  if(datain){activationoutput();}
  datain=0;
  if (Serial.available())
   {
      str = Serial.readStringUntil('\n');
     // #IFDEBUG Serial.print(str);
   }  
  delay(1000);
}

void activationoutput()  
{
  if (go_front)
  {digitalWrite(motorUnoA, HIGH);
   digitalWrite(motorUnoB, LOW);
   digitalWrite(motorDosA, HIGH);
   digitalWrite(motorDosB, LOW);
  }
  
  if (go_back)
  {
   digitalWrite(motorUnoA, LOW);
   digitalWrite(motorUnoB, HIGH);
   digitalWrite(motorDosA, LOW);
   digitalWrite(motorDosB, HIGH);}
  
  if (go_left)
  {
   digitalWrite(motorUnoA, HIGH);
   digitalWrite(motorUnoB, LOW);
   digitalWrite(motorDosA, LOW);
   digitalWrite(motorDosB, HIGH);}
     
  if (go_right)
  {
   digitalWrite(motorUnoA, LOW);
   digitalWrite(motorUnoB, HIGH);
   digitalWrite(motorDosA, HIGH);
   digitalWrite(motorDosB, LOW);}

  if (!go_right&!go_left&!go_back&!go_front)
  {
   digitalWrite(motorUnoA, LOW);
   digitalWrite(motorUnoB, LOW);
   digitalWrite(motorDosA, LOW);
   digitalWrite(motorDosB, LOW);}
 }
  

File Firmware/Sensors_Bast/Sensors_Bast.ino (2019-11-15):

/************************************************************
  SPANISH
  Sensor Bast 1.0.1
  Cat Finder - Rover Educativo
  Rocio Rosales @ Electronic Cats
  Eduardo Contreras @ Electronic Cats
  Original Creation Date: Sep 23, 2019
  https://github.com/ElectronicCats/Cat_Finder

  Este ejemplos demuestra el funcionamiento basico de los sensores y funcionalidad
  basica del Cat Finder Kit de Rover Educativo
  http://electroniccats.com

  Especificaciones del entorno de Desarrollo:
  IDE: Arduino 1.8.9
  Plataforma de Hardware:
  Kit Cat Finder
  - Bast Pro Mini M0
  - BMP280
  - CCS811
  - MPU6050
  - HMC5883


  Este código es beerware si tu me ves ( o cualquier otro miembro de Electronic Cats)
  a nivel local, y tu has encontrado nuestro código útil ,
  por favor comprar una ronda de cervezas!

  Distribuido como; no se da ninguna garantía.
************************************************************/

/************************************************************
  ENGLISH
  Sensor Bast 1.0.1
  Cat Finer - Rover
  Rocio Rosales @ Electronic Cats
  Eduardo Contreras @ Electronic Cats
  Original Creation Date: Sep 23, 2019
  https://github.com/ElectronicCats/Cat_Finder

  This example demonstrates how to use program Bast read I2C sensors

  Development environment specifics:
  IDE: Arduino 1.8.9
  Hardware Platform:
  Kit Can Finder
  - Bast Pro Mini M0
  - BMP280
  - CCS811
  - MPU6050
  - QMC5883L

  This code is beerware; if you see me (or any other Electronic Cats
  member) at the local, and you've found our code helpful,
  please buy us a round!

  Distributed as-is; no warranty is given.
*/

#include <Wire.h>
#include "SparkFunBME280.h"
#include "Adafruit_CCS811.h"
#include <MPU6050.h>  //acelerometro y gyroscopio
#include <QMC5883LCompass.h>  //Magnetometro

#define Serial SerialUSB

//Variables BME280
float humidity=0;
float pressure=0;
float temp=0;

//Variables CCS811
float co2=0;
float tvoc=0;

//Variables HMC5883L
float magX=0;
float magY=0;
float magZ=0;

BME280 mySensorB;//Object BME280
Adafruit_CCS811 ccs; //Object CCS811

MPU6050 accelgyro;
//Variables de Aceleración y Giroscopio
//Accel and Gyro Vars
int16_t ax, ay, az;
int16_t gx, gy, gz;


QMC5883LCompass compass; //Magnetometro
int mx, my, mz;

String Todo;

void setup()
{
  Wire.begin();

  Serial.begin(115200);
  Serial1.begin(115200);
  
  //while(!Serial);

  //BME280 CONFIG
   mySensorB.setI2CAddress(0x76); //Connect to a second sensor
   if(mySensorB.beginI2C() == false) Serial.println("Sensor BME280 connect failed");

  //CCS811 config
  if(!ccs.begin()){
    Serial.println("Failed to start sensor CCS811! Please check your wiring.");
    while(1);
     }

  //Inicializar acelerometro y gyroscopio
  accelgyro.initialize();  /// Initialize MPU

  accelgyro.setI2CMasterModeEnabled(false);
  accelgyro.setI2CBypassEnabled(true) ;
  accelgyro.setSleepEnabled(false);

  // Initialise mag
  compass.init();
}

void loop()
{ 
  //Variables BME280
  humidity=mySensorB.readFloatHumidity();
  pressure=mySensorB.readFloatPressure();
  temp=mySensorB.readTempC();


  //data CCS811
  if(ccs.available()){
    if(!ccs.readData()){
      co2=ccs.geteCO2();
      tvoc=ccs.getTVOC();
    }
    else{
      Serial.println("ERROR!");
      while(1);
    }
  }
  
  accelgyro.getMotion6(&ax, &ay, &az, &gx, &gy, &gz);
  
  // Read compass values
  compass.read();

  // Return XYZ readings
  mx = compass.getX();
  my = compass.getY();
  mz = compass.getZ();

  //send all data
    Todo+=humidity;
    Todo+=",";
    Todo+=pressure;
    Todo+=",";
    Todo+=temp;//°C
    Todo+=",";
    Todo+=co2;//ppm
    Todo+=",";
    Todo+=tvoc;//ppb
    Todo+=",";
    Todo+=ax;
    Todo+=",";
    Todo+=ay;
    Todo+=",";
    Todo+=az;
    Todo+=",";
    Todo+=gx;
    Todo+=",";
    Todo+=gy;
    Todo+=",";
    Todo+=gz;
    Todo+=",";
    Todo+=mx;
    Todo+=",";
    Todo+=my;
    Todo+=",";
    Todo+=mz;
    Serial.println(Todo);
    Serial1.println(Todo);
    Todo = "";

  delay(1000);
}

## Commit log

2019-07-02 initial kicad and .ino
    [rover_car.kicad_pcb, rover_car.sch]
2019-07-03 At schematic
    [rover_car.sch]
2019-07-04 add file.por rover main
    [rover_main.kicad_pcb, rover_main.sch]
2019-07-05 circuit regulation
    [rover_main.sch]
2019-07-05 Add pcb and edit sch
    [rover_car.kicad_pcb, rover_car.sch]
2019-07-08 add battery charger
2019-07-09 PCB rover v0.1
    [rover_car.kicad_pcb, rover_car.sch]
2019-07-11 Add capacitor
    [rover_car.kicad_pcb, rover_car.sch]
2019-07-15 Last Revision pcb
    [rover_car.kicad_pcb]
2019-07-18 asig SDA and SCL
    [rover_main.sch]
2019-07-22 Last revision
    [rover_car.kicad_pcb, rover_car.sch]
2019-07-22 add footprints and manf#
    [rover_main.sch]
2019-07-22 Accommodation revision
    [rover_car.kicad_pcb]
2019-07-22 antena wifi without cobre
    [rover_main.sch]
2019-07-23 change V batt
    [rover_main.sch]
2019-07-23 change diode in pcb
    [rover_main.kicad_pcb]
2019-07-23 Track revision
    [PCB.kicad_pcb, PCB.sch, rover_car.kicad_pcb]
2019-07-24 Change tracks
    [rover_car.kicad_pcb]
2019-08-02 fix corners
    [rover_car.kicad_pcb, rover_car.sch]
2019-08-02 add button back and front
2019-08-02 Fix component number and etching
    [rover_car.kicad_pcb, rover_car.sch]
2019-08-02 add left and right button
2019-08-03 Update PCB version 1.0
    [rover_car.kicad_pcb, rover_car.sch]
2019-08-05 add bast schematic
    [rover_main.sch]
2019-08-06 Asig. places componets
    [rover_main.kicad_pcb, rover_main.sch]
2019-08-06 Update traces
    [rover_main.kicad_pcb, rover_main.sch]
2019-08-06 ADD DIODE
    [_saved_rover_main.sch, rover_main.kicad_pcb]
2019-08-06 move V track
    [_saved_rover_main.sch, rover_main.kicad_pcb, rover_main.sch]
2019-08-07 Add SDA to jumper
    [rover_main.kicad_pcb, rover_main.sch]
2019-08-07 Update traces and placement
    [rover_main.kicad_pcb]
2019-08-07 move labels
    [rover_main.kicad_pcb]
2019-08-07 Sensors tables
    [rover_main.kicad_pcb]
2019-08-07 move edge cuts ESP32
    [rover_main.kicad_pcb]
2019-08-08 change jumper open in sch
    [rover_main.sch]
2019-08-08 edit names and manf#
    [_saved_rover_car.sch]
2019-08-08 save changes
    [_saved_rover_car.sch, rover_car.sch]
2019-08-14 fix conections CCS811
    [rover_main.sch]
2019-08-14 rerouting CCS811
    [rover_main.kicad_pcb]
2019-08-14 clean layer
    [rover_main.kicad_pcb]
2019-08-27 add laber to sensor data
2019-08-27 label sensor data
2019-08-28 change name rover to cat_finder
    [PCB.kicad_pcb, PCB.sch, rover_car.kicad_pcb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]
2019-08-28 change name rover_car to cat_finder_drivers
    [PCB.kicad_pcb, PCB.sch, cat_finder_drivers.kicad_pcb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]
2019-08-28 change name
    [cat_finder_main.kicad_pcb, cat_finder_main.sch]
2019-09-01 change CCS811
    [cat_finder_main.kicad_pcb]
2019-09-01 fix charger
    [cat_finder_main.sch]
2019-09-01 labels battery
    [cat_finder_main.kicad_pcb]
2019-09-03 change drill esp32
    [cat_finder_main.kicad_pcb, cat_finder_main.sch]
2019-09-03 add switch
    [cat_finder_main.kicad_pcb, cat_finder_main.sch]
2019-09-05 change prog pines delete switch
    [cat_finder_main.kicad_pcb, cat_finder_main.sch]
2019-09-05 add swich on/off
    [cat_finder_main.kicad_pcb, cat_finder_main.sch]
2019-09-05 add pin bast
    [cat_finder_main.kicad_pcb, cat_finder_main.sch]
2019-09-06 fix memory esp32
2019-09-09 move diode
    [cat_finder_main.kicad_pcb]
2019-09-09 fix conection A1
    [cat_finder_main.kicad_pcb]
2019-09-10 add diode VCC
    [_saved_cat_finder_main.sch, cat_finder_main.kicad_pcb]
2019-09-10 move tracks
    [cat_finder_main.kicad_pcb, cat_finder_main.sch]
2019-09-10 change name drivers to motors
    [cat_finder_motors.kicad_pcb, cat_finder_motors.sch]
2019-09-10 delate cache
    [_saved_cat_finder_main.sch]
2019-09-10 add labels
    [cat_finder_main.kicad_pcb]
2019-09-10 change diode´s name
    [cat_finder_main.sch]
2019-09-12 Add MOSFET
    [cat_finder_main.kicad_pcb, cat_finder_main.sch]
2019-09-12 clean FCu BCu
    [cat_finder_main.kicad_pcb]
2019-09-13 change transistor
    [cat_finder_main.sch]
2019-09-13 change transistor pcb
    [cat_finder_main.kicad_pcb, cat_finder_main.sch]
2019-09-17 Update diode
    [cat_finder_main.kicad_pcb, cat_finder_main.sch]
2019-09-25 print string in server
2019-09-27 add schematic PDF
2019-09-29 Add 3d parts
    [cat_finder_motors.stp]
2019-09-29 Add Electronics folder
    [cat_finder_main.kicad_pcb, cat_finder_main.sch, cat_finder_motors.kicad_pcb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]
2019-09-29 Add mechanics folder and 3D printing
    [Ruedas_Suport.STL, Tapon1.SLDPRT, Tapon1.STL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]
2019-09-29 Add solid works files
    [Acrilico Base.SLDPRT, Acrilico frontal.SLDPRT, Acrilico.SLDPRT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]
2019-10-07 update name
    [Ruedas_Suport.STL, Tapon1.STL, Tapon2.STL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]
2019-10-13 Fix paths
    [cat_finder_main.kicad_pcb, cat_finder_main.sch, cat_finder_motors.kicad_pcb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]
2019-11-11 Best description error and add version
    [Sensors_Bast.ino]
2019-11-12 Migrate to QMC5883L
    fix error with GY-87
    [Sensors_Bast.ino]
2019-11-21 working in core ESP32 1.0.2
2020-02-06 Add program for Bast Pro mini to update the ESP32
